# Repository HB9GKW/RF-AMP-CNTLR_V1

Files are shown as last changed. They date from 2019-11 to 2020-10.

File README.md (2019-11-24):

# RF-AMP-CNTLR_V1
HB9GKW RF Amplifier Controller

Features:

* Save sequencing of: 
	- Input and output relays with handshake and adjustable delays
	- Amplifier gate enable
	- ALC blanking voltage

* Control of up to 2 power amplifier modules

* Fast analog interlocking:
	- 4x VSWR
	- 2x RF input overload
	- Overcurrent
	- 2x Temperature

* High power MOSFET high side switch with voltage/current sense to disable amplifiers drain supply

* PTT input and adjustable ALC output

* Digital monitoring interface compatible for Raspberry Pi (40 pin header):
	- Amplifier operation and fault states
	- 12 ADC channels (12bit) for voltage, current, 4x forward/reflected, 2x temperature reading

* On-board power supplies (12V, -12V, 5V, 3.3V)

* Can be powered either by mains or external 13.8V supply

* Enhanced RF relay switching speed circuitry compatible for 12V and 24V RF relays

* Radio CAT control, Band and Antenna switching and general purpose interfacing ports for I2C and SPI

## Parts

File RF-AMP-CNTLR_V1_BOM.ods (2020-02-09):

Source: | RF-AMP-CNTLR_V1.sch
Date: | Sat 18 Jan 2020 12:43:05 PM CET
Tool: | Eeschema 5.1.5+dfsg1-2~bpo10+1
Generator: | /usr/share/kicad/plugins/bom_csv_grouped_by_value_with_fp.py
Component Count: | 375
Ref | Qnty | Value | Cmp name | Footprint | Description | Distributor | Distributor Order Number
C101, C106, C107, C114, C115, C116, C117, C118, C119, C123, C201, C203, C204, C205, C206, C207, C208, C209, C301, C310, C311, C312, C401, C402, C405, C406, C407, C408, C409, C410, C411, C412, C413, C414, C415, C416, C417, C418, C419, C423, C427, | 41 | 100n | C | Capacitor_SMD:C_0805_2012Metric_Pad1.15x1.40mm_HandSolder | Unpolarized capacitor | Mouser
C102, C103, | 2 | 68n | C | Capacitor_THT:C_Rect_L13.0mm_W4.0mm_P10.00mm_FKS3_FKP3_MKS4 | Unpolarized capacitor | Mouser | R71VF26804030K (https://www.mouser.ch/ProductDetail/KEMET/R71VF26804030K)
C104, C105, C110, C111, C112, C113, C120, C121, C122, C202, | 10 | 47u | CP | Capacitor_Tantalum_SMD:CP_EIA-6032-28_Kemet-C | Polarized capacitor | Mouser
C108, C109, | 2 | 47n | C | Capacitor_THT:C_Rect_L7.0mm_W3.5mm_P5.00mm | Unpolarized capacitor | Mouser | MKP2J024701M00KSSD (https://www.mouser.ch/ProductDetail/WIMA/MKP2J024701M00KSSD?qs=sGAEpiMZZMv1cc3ydrPrF7l45uRd9dVhKRMPc5zgiSQ%3D)
C302, C303, C304, C305, C306, C307, C308, C309, C313, C314, C315, C316, | 12 | 47n | C | Capacitor_SMD:C_0805_2012Metric_Pad1.15x1.40mm_HandSolder | Unpolarized capacitor | Mouser
C403, C404, | 2 | 470u | CP | Capacitor_THT:CP_Radial_D22.0mm_P10.00mm_SnapIn | Polarized capacitor | Mouser | MAL215932471E3 (https://www.mouser.ch/ProductDetail/Vishay-BC-Components/MAL215932471E3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)
C420, C421, C424, C425, | 4 | 1u | C | Capacitor_SMD:C_0805_2012Metric_Pad1.15x1.40mm_HandSolder | Unpolarized capacitor | Mouser
C422, C426, | 2 | 4u7 | CP | Capacitor_Tantalum_SMD:CP_EIA-6032-28_Kemet-C | Polarized capacitor | Mouser
D101, | 1 | B80C800DM | B80C800DM | Diode_THT:Diode_Bridge_DIP-4_W7.62mm_P5.08mm | Glass Passivated Single-Phase Bridge Rectifier, 80V Vrms, 0.8A If, DIP-4 | Mouser | B80C800DM-E3/45 (https://www.mouser.ch/ProductDetail/Vishay-Semiconductors/B80C800DM-E3-45)
D102, D202, | 2 | Power, RP_ON | LED | LED_THT:LED_D3.0mm | Light emitting diode, green | Mouser
D103, D104, D309, | 3 | BAT54CW | BAT54CW | Package_TO_SOT_SMD:SOT-323_SC-70 | Dual schottky barrier diode, common cathode, SOT-323 | Mouser | BAT54CWT1G (https://www.mouser.ch/ProductDetail/ON-Semiconductor/BAT54CWT1G)
D201, | 1 | BAT54AW | BAT54AW | Package_TO_SOT_SMD:SOT-323_SC-70 | Dual schottky barrier diode, common anode, SOT-323 | Mouser | BAT54AWT1G (https://www.mouser.ch/ProductDetail/ON-Semiconductor/BAT54AWT1G)
D305, D306, D307, D308, D314, D315, D316, D317, D319, D403, D404, D406, D409, D410, D413, D414, | 16 | BZT52C4V7T-7 | BZT52C4V7T-7 | Diode_SMD:D_SOD-523 | 150mW Silicon Planar Zener Diode, 4.7V, SOD-523 | Mouser | BZT52C4V7T-7 (https://www.mouser.ch/ProductDetail/Diodes-Incorporated/BZT52C4V7T-7)
D301, D302, D303, D304, D310, D311, D312, D313, D318, | 9 | HSWR1, HSWR2, HSWR3, HSWR4, RF_OL, TEMP1, TEMP2, OC, FAULT | LED | LED_THT:LED_D3.0mm | Light emitting diode, red | Mouser
D401, | 1 | Z1SMA33 | Z1SMAxxx | Diode_SMD:D_SMA | 1000mW Zener Diode, SMA(DO-214AC) | Mouser | SZ1SMA33AT3G (https://www.mouser.ch/ProductDetail/Littelfuse/SZ1SMA33AT3G)
D402, D405, | 2 | DZ2S130X0L | DZ2S130X0L | Diode_SMD:D_SOD-523 | 150mW Silicon Planar Zener Diode, 13V, SOD-523 | Mouser | BZT52C13T-7 (https://www.mouser.ch/ProductDetail/Diodes-Incorporated/BZT52C13T-7)
D407, D408, D411, D412, | 4 | PMEG6010CEH | PMEG6010CEH | Diode_SMD:D_SOD-123 | 60V 1A very low Vf MEGA Schottky barrier rectifier, SOD-123 | Mouser | PMEG6010CEH,115 (https://www.mouser.ch/ProductDetail/Nexperia/PMEG6010CEH115)
F101, F102, | 2 | 0.1AT | Fuse | Fuse:Fuse_Littelfuse_372_D8.50mm | Fuse | Mouser | 37211000001 (https://www.mouser.ch/ProductDetail/Littelfuse/37211000001)
FL101, | 1 | EMI_Filter_CommonMode | EMI_Filter_CommonMode | Inductor_THT:Choke_Schaffner_RN202-04-8.8x18.2mm | EMI 2-inductor common mode filter | Mouser | RN202-0.6-02-4M4 (https://www.mouser.ch/ProductDetail/Schaffner/RN202-06-02-4M4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)
J101, J102, J110, J111, | 4 | VAC, VDC, RELAY RF OUT, RELAY RF IN, | Screw_Terminal_01x06 | TerminalBlock_Phoenix:TerminalBlock_Phoenix_MKDS-3-6-5.08_1x06_P5.08mm_Horizontal | Generic screw terminal, single row, 01x06, script generated (kicad-library-utils/schlib/autogen/connector/) | Mouser | 1729160 (https://www.mouser.de/ProductDetail/Phoenix-Contact/1729160)
J103, | 1 | ext_13V8 | Screw_Terminal_01x02 | TerminalBlock_Phoenix:TerminalBlock_Phoenix_MKDS-3-2-5.08_1x02_P5.08mm_Horizontal | Generic screw terminal, single row, 01x02, script generated (kicad-library-utils/schlib/autogen/connector/) | Mouser
J104, J123, J124, | 3 | Front Panel, AMP1, AMP2, | Conn_02x08_Odd_Even | Connector_Multicomp:Multicomp_MC9A12-1634_2x08_P2.54mm_Vertical | Generic connector, double row, 02x08, odd/even pin numbering scheme (row 1 odd numbers, row 2 even numbers), script generated (kicad-library-utils/schlib/autogen/connector/) | Mouser
J105, J107, J121, J122, | 4 | ANT_SWITCH, I2C0, I2C1, RS232, | Conn_01x06 | Connector_PinHeader_2.54mm:PinHeader_1x06_P2.54mm_Vertical | Generic connector, single row, 01x06, script generated (kicad-library-utils/schlib/autogen/connector/) | Mouser
J106, J120, | 2 | BAND_SELECT, SPI0 | Conn_01x08 | Connector_PinHeader_2.54mm:PinHeader_2x04_P2.54mm_Vertical | Generic connector, single row, 01x08, script generated (kicad-library-utils/schlib/autogen/connector/) | Mouser
J108, J109, J118, J119, | 4 | VDD_IN, VSS_IN, VDD_AMP, GND_AMP, | Screw_Terminal_01x01 | TerminalBlock_MetzConnect:TerminalBlock_MetzConnect_360425_1x01_Horizontal_ScrewM4.0_Boxed | Generic screw terminal, single row, 01x01, script generated (kicad-library-utils/schlib/autogen/connector/) | Mouser
J112, J113, J114, J115, J116, J117, | 6 | FWD3, REF3, FWD4, REF4, PTT, ALC, | Conn_Coaxial | Connector_Coaxial:SMA_Amphenol_132134_Vertical | coaxial connector (BNC, SMA, SMB, SMC, Cinch/RCA, ...) | Mouser
J201, | 1 | Raspberry_Pi_2_3 | Raspberry_Pi_2_3 | Connector_PinHeader_2.54mm:PinHeader_2x20_P2.54mm_Vertical | expansion header for Raspberry Pi 2 & 3 | Mouser
L101, L102, L103, L104, | 4 | 10u | L_Core_Ferrite | Inductor_SMD:L_TDK_SLF6045 | Inductor with ferrite core | Mouser
PS101, PS102, | 2 | IRM-20-12 | IRM-20-12 | Converter_ACDC:Converter_ACDC_MeanWell_IRM-20-xx_THT | 12V 1.8A 20W miniature AC-DC module-type power supply MeanWell | Mouser | IRM-20-12 (https://www.mouser.de/ProductDetail/MEAN-WELL/IRM-20-12)
PS103, | 1 | IRM-20-5 | IRM-20-5 | Converter_ACDC:Converter_ACDC_MeanWell_IRM-20-xx_THT | 5V 4A 20W miniature AC-DC module-type power supply MeanWell | Mouser | RM-20-5 (https://www.mouser.de/ProductDetail/MEAN-WELL/IRM-20-5)
PS104, | 1 | ITQ2412SA | ITQ2412SA | my-library-footprints:Converter_DCDC_XP_POWER-ITXxxxxSA_THT | XP Power 6W, 1000 VDC Isolated DC/DC Converter Module, Single Output Voltage 12V, ±500mA, 24V Input Voltage, SIP | Mouser | ITQ2412SA (https://www.mouser.de/ProductDetail/XP-Power/ITQ2412SA)
PS105, | 1 | ITQ2405SA | ITQ2405SA | my-library-footprints:Converter_DCDC_XP_POWER-ITXxxxxSA_THT | XP Power 6W, 1000 VDC Isolated DC/DC Converter Module, Single Output Voltage 5V, ±1200mA, 24V Input Voltage, SIP | Mouser | ITQ2405SA (https://www.mouser.de/ProductDetail/XP-Power/ITQ2405SA)
Q101, Q321, Q322, Q332, Q408, Q411, Q413, Q417, Q421, Q425, | 10 | DTA124E | DTA124E | Package_TO_SOT_SMD:SOT-23 | Digital PNP Transistor, 22k/22k, SOT-23 | Mouser | PDTA124ET,215 (https://www.mouser.ch/ProductDetail/Nexperia/PDTA124ET215)
Q201, Q202, | 2 | BSS138 | BSS138 | Package_TO_SOT_SMD:SOT-23 | 50V Vds, 0.22A Id, N-Channel MOSFET, SOT-23 | Mouser | BSS138LT7G (https://www.mouser.de/ProductDetail/ON-Semiconductor/BSS138LT7G)
Q301, Q302, Q303, Q304, Q305, Q306, Q307, Q308, Q309, Q310, Q311, Q312, Q317, Q318, Q319, Q320, Q323, Q324, Q404, | 19 | BC857 | BC857 | Package_TO_SOT_SMD:SOT-23 | 0.1A Ic, 45V Vce, PNP Transistor, SOT-23 | Mouser
Q313, Q314, Q315, Q316, Q325, Q326, Q327, Q328, Q329, Q330, Q331, Q403, Q405, Q406, Q407, Q409, Q410, Q414, Q415, Q418, Q419, Q422, Q423, Q424, Q427, Q428, Q429, | 27 | DTC124E | DTC124E | Package_TO_SOT_SMD:SOT-23 | Digital NPN Transistor, 22k/22k, SOT-23 | Mouser | PDTC124ET,215 (https://www.mouser.ch/ProductDetail/Nexperia/PDTC124ET215)
Q401, Q402, | 2 | IXTH140P10T | SUD50P08-25L | Package_TO_SOT_THT:TO-247-3_Vertical | 50A Id, 80V Vds, TrenchFET P-Channel Power MOSFET, 25.2mOhm Ron, 160nC Qg, -55 to 175 °C, TO-252-2 | Mouser | IXTH140P10T (https://www.mouser.de/ProductDetail/IXYS/IXTH140P10T)
Q412, Q416, Q420, Q426, | 4 | BCX53 | BCX53 | Package_TO_SOT_SMD:SOT-89-3 | 1A Ic, 80V Vce, PNP Medium Power Transistor, SOT-89 | Mouser | BCX53-16TX (https://www.mouser.de/ProductDetail/Nexperia/BCX53-16TX)
R101, R325, R326, R327, R328, R333, R334, R335, R336, R363, R364, R365, R366, R378, | 14 | 22k | R | Resistor_SMD:R_0805_2012Metric_Pad1.15x1.40mm_HandSolder | Resistor | Mouser
R102, R377, R412, R415, R417, R424, R425, R432, R433, R434, R435, R436, R437, | 13 | 1k | R | Resistor_SMD:R_0805_2012Metric_Pad1.15x1.40mm_HandSolder | Resistor | Mouser
R103, | 1 | 620 | R | Resistor_SMD:R_0805_2012Metric_Pad1.15x1.40mm_HandSolder | Resistor | Mouser
R104, R201, R202, | 3 | 2k2 | R | Resistor_SMD:R_0805_2012Metric_Pad1.15x1.40mm_HandSolder | Resistor | Mouser
R203, | 1 | 1k5 | R | Resistor_SMD:R_0805_2012Metric_Pad1.15x1.40mm_HandSolder | Resistor | Mouser
R204, R205, R206, | 3 | 2k7 | R | Resistor_SMD:R_0805_2012Metric_Pad1.15x1.40mm_HandSolder | Resistor | Mouser
R207, R208, | 2 | 1k8 | R | Resistor_SMD:R_0805_2012Metric_Pad1.15x1.40mm_HandSolder | Resistor | Mouser
R301, R302, R303, R304, R305, R306, R307, R308, R353, R356, R359, R360, R361, R362, R403, R409, R414, | 17 | 100k | R | Resistor_SMD:R_0805_2012Metric_Pad1.15x1.40mm_HandSolder | Resistor | Mouser
R309, R310, R311, R312, R350, R352, | 6 | 15k | R | Resistor_SMD:R_0805_2012Metric_Pad1.15x1.40mm_HandSolder | Resistor | Mouser
R313, R314, R315, R316, | 4 | 82k | R | Resistor_SMD:R_0805_2012Metric_Pad1.15x1.40mm_HandSolder | Resistor | Mouser
R317, R318, R319, R320, R349, R351, R354, R357, R379, R411, R418, R421, R426, R429, | 14 | 47k | R | Resistor_SMD:R_0805_2012Metric_Pad1.15x1.40mm_HandSolder | Resistor | Mouser
R321, R322, R323, R324, R337, R339, R341, R343, R355, R358, R367, R371, R404, R410, R413, R419, R420, R422, R423, R427, R428, R430, R431, | 23 | 10k | R | Resistor_SMD:R_0805_2012Metric_Pad1.15x1.40mm_HandSolder | Resistor | Mouser
R329, R330, R331, R332, | 4 | 820k | R | Resistor_SMD:R_0805_2012Metric_Pad1.15x1.40mm_HandSolder | Resistor | Mouser
R338, R340, R342, R344, R368, R369, R370, R372, R380, R407, | 10 | 4k7 | R | Resistor_SMD:R_0805_2012Metric_Pad1.15x1.40mm_HandSolder | Resistor | Mouser
R345, R346, R347, R348, R373, R374, R375, R376, R381, | 9 | 470 | R | Resistor_SMD:R_0805_2012Metric_Pad1.15x1.40mm_HandSolder | Resistor | Mouser
R401, R402, R405, | 3 | 0R015 | R | Resistor_SMD:R_Shunt_Vishay_WSR2_WSR3_KelvinConnection | Resistor | Mouser | WSR3R0150FEB (https://www.mouser.ch/ProductDetail/Vishay-Dale/WSR3R0150FEB)
R406, | 1 | 6k8 | R | Resistor_SMD:R_0805_2012Metric_Pad1.15x1.40mm_HandSolder | Resistor | Mouser
R408, | 1 | 68k | R | Resistor_SMD:R_0805_2012Metric_Pad1.15x1.40mm_HandSolder | Resistor | Mouser
R416, | 1 | 33k | R | Resistor_SMD:R_0805_2012Metric_Pad1.15x1.40mm_HandSolder | Resistor | Mouser
RV301, RV302, RV303, RV304, RV305, RV306, RV307, RV308, | 8 | 50k | R_POT_TRIM | Potentiometer_THT:Potentiometer_Bourns_3296W_Vertical | Trim-potentiometer | Mouser
RV401, RV402, RV403, RV404, RV405, | 5 | 20k | R_POT_TRIM | Potentiometer_THT:Potentiometer_Bourns_3296W_Vertical | Trim-potentiometer | Mouser
SW301, | 1 | RESET | SW_Push | Button_Switch_THT:SW_PUSH_6mm | Push button switch, generic, two pins | Mouser
U101, | 1 | KA378R12C | KA378R12C | Package_TO_SOT_THT:TO-220-4_Vertical | Positive 3A 35V Linear Regulator with Disable Pin, LDO, Fixed Output 12V, TO-220F-4L | Mouser | obsolete | KIA378R12PI | eBay | MIC29301-12WT
U102, | 1 | SFH617A-2 | SFH617A-2 | Package_DIP:DIP-4_W7.62mm | Optocoupler, Phototransistor Output, 5300 VRMS, VCEO 70V, CTR% 63-125, -55 to +110 degree Celcius, UL, BSI, FIMKO, cUL, THT PDIP-4 | Mouser | VO617A-2 (https://www.mouser.de/ProductDetail/Vishay-Semiconductors/VO617A-2)
U103, | 1 | L78L33_SOT89 | L78L33_SOT89 | Package_TO_SOT_SMD:SOT-89-3 | Positive 100mA 30V Linear Regulator, Fixed Output 3.3V, SOT-89 | Mouser | L78L33ABUTR (https://www.mouser.de/ProductDetail/STMicroelectronics/L78L33ABUTR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)
U201, | 1 | MCP23017_SO | MCP23017_SO | Package_SO:SOIC-28W_7.5x17.9mm_P1.27mm | 16-bit I/O expander, I2C, interrupts, w pull-ups, SOIC-28 | Mouser | MCP23017-E/SO (https://www.mouser.de/ProductDetail/Microchip-Technology/MCP23017-E-SO)
U202, | 1 | MAX11616 | MAX11616 | Package_SO:QSOP-16_3.9x4.9mm_P0.635mm | 12-channel single-ended or 6-channel, differential, 12-bit ADC, I2C, 4.096V internal reference, 16-QSOP package | Mouser | MAX11616EEE+ (https://www.mouser.de/ProductDetail/Maxim-Integrated/MAX11616EEE%2B)
U203, | 1 | MAX3232 | MAX3232 | Package_SO:SOIC-18W_7.5x11.6mm_P1.27mm | 3.0V to 5.5V, Low-Power, up to 1Mbps, True RS-232 Transceivers Using Four 0.1μF External Capacitors | Mouser | MAX3222CWN+T (https://www.mouser.ch/ProductDetail/Maxim-Integrated/MAX3222CWN%2BT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)
U301, U304, U404, | 3 | LM339 | LM339 | Package_SO:SOIC-14_3.9x8.7mm_P1.27mm | Quad Differential Comparators, DIP-14/SOIC-14/SSOP-14 | Mouser | LM339DT (https://www.mouser.de/ProductDetail/STMicroelectronics/LM339DT?qs=sGAEpiMZZMsmUjwTDAf1t%252Bwcp%2FHLv31N)
U302, U303, U402, | 3 | MC33079 | MC33079 | Package_SO:SOIC-14_3.9x8.7mm_P1.27mm | Low Noise, Quad Operational Amplifiers, DIP-14/SOIC-14 | Mouser | MC33079DR2G (https://www.mouser.de/ProductDetail/ON-Semiconductor/MC33079DR2G?qs=sGAEpiMZZMtqO%252BWUGLBzeDrZ6oZu72DA)
U401, | 1 | MC33078 | MC33078 | Package_SO:SOIC-8_3.9x4.9mm_P1.27mm | Low Noise, Dual Operational Amplifiers, DIP-8/SOIC-8/SSOP-8 | Mouser | MC33078DR2G (https://www.mouser.de/ProductDetail/ON-Semiconductor/MC33078DR2G?qs=sGAEpiMZZMtqO%252BWUGLBzeFSiTRByazFb)
U403, | 1 | INA138 | INA138 | Package_TO_SOT_SMD:SOT-23-5 | High-Side Measurement Current Shunt Monitor, 36V, SOT-23-5 | Mouser | INA138NA/3K (https://www.mouser.de/ProductDetail/Texas-Instruments/INA138NA-3K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)

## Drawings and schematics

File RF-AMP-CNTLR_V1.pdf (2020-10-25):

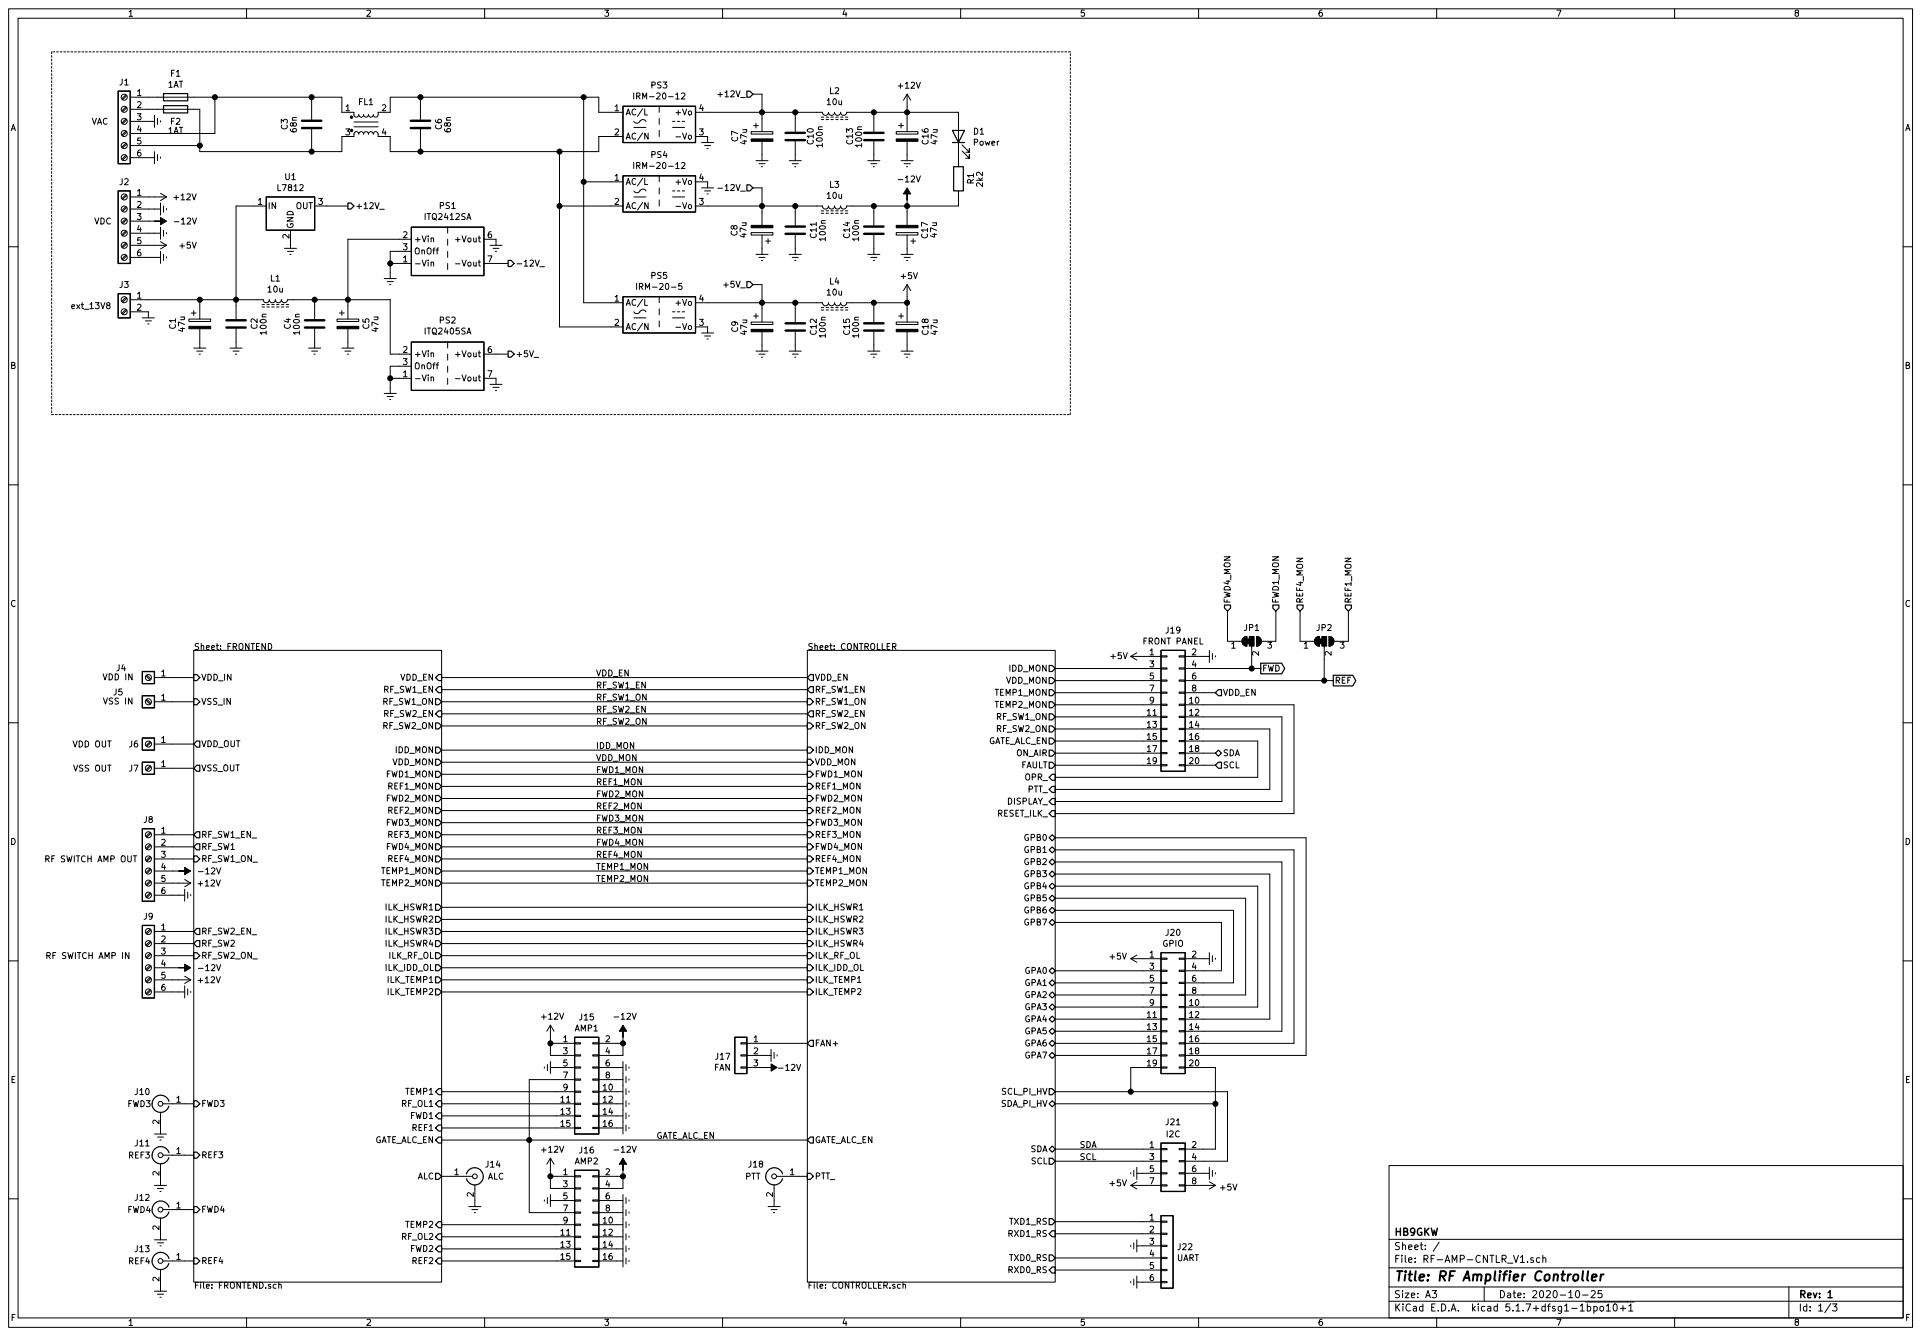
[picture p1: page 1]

RF_SW2_ON | | 13 | | 14
IDD_MON | | 15 | | 16

11 | 12
13 | 14
15 | 16
17 | 18

File: RF-AMP-CNTLR_V1.sch Sheet: / HB9GKW

Id: 1/3 Title: RF Amplifier Controller

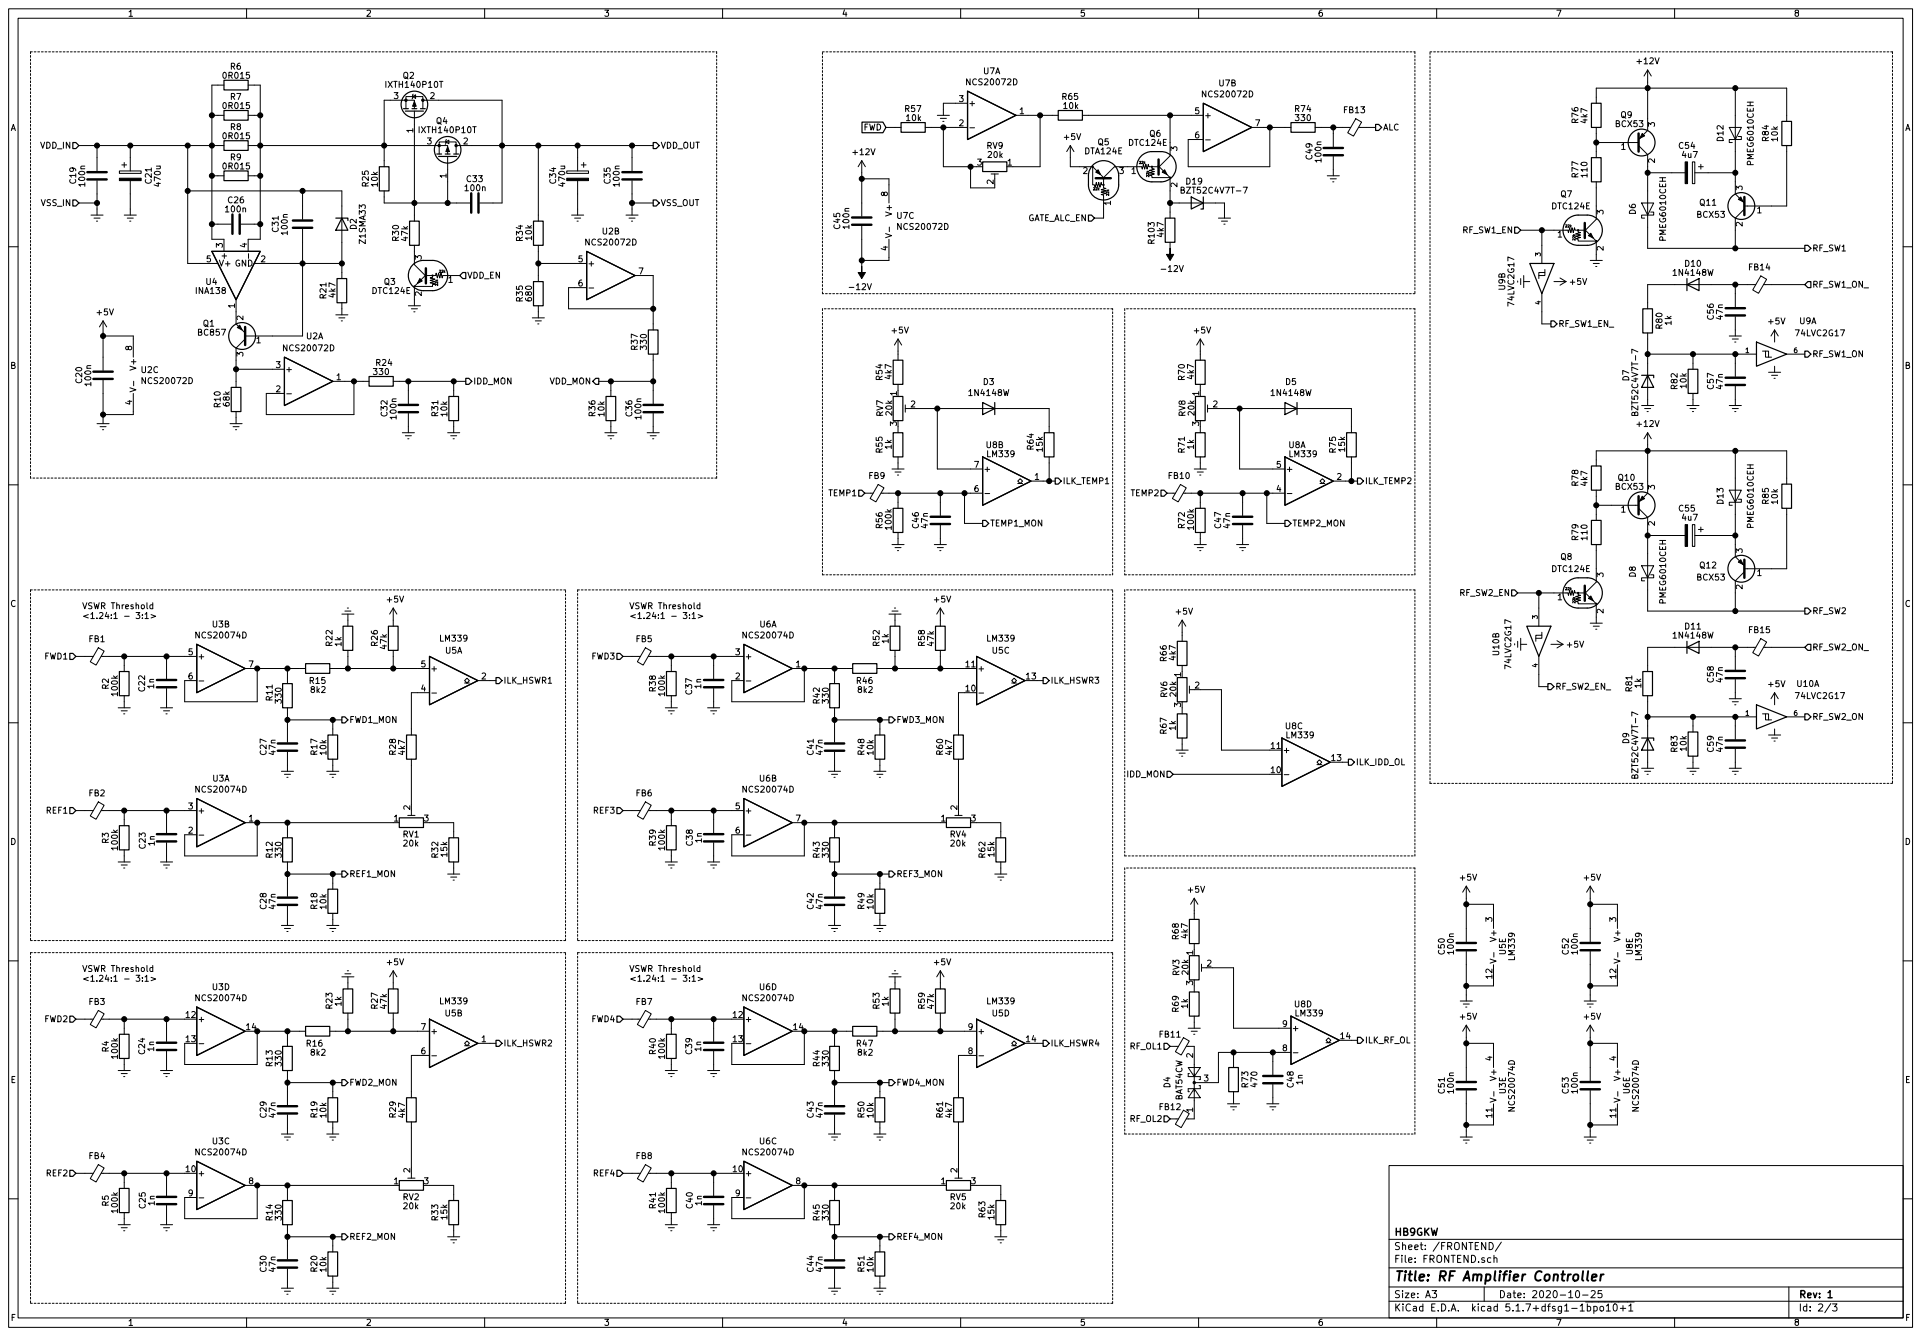
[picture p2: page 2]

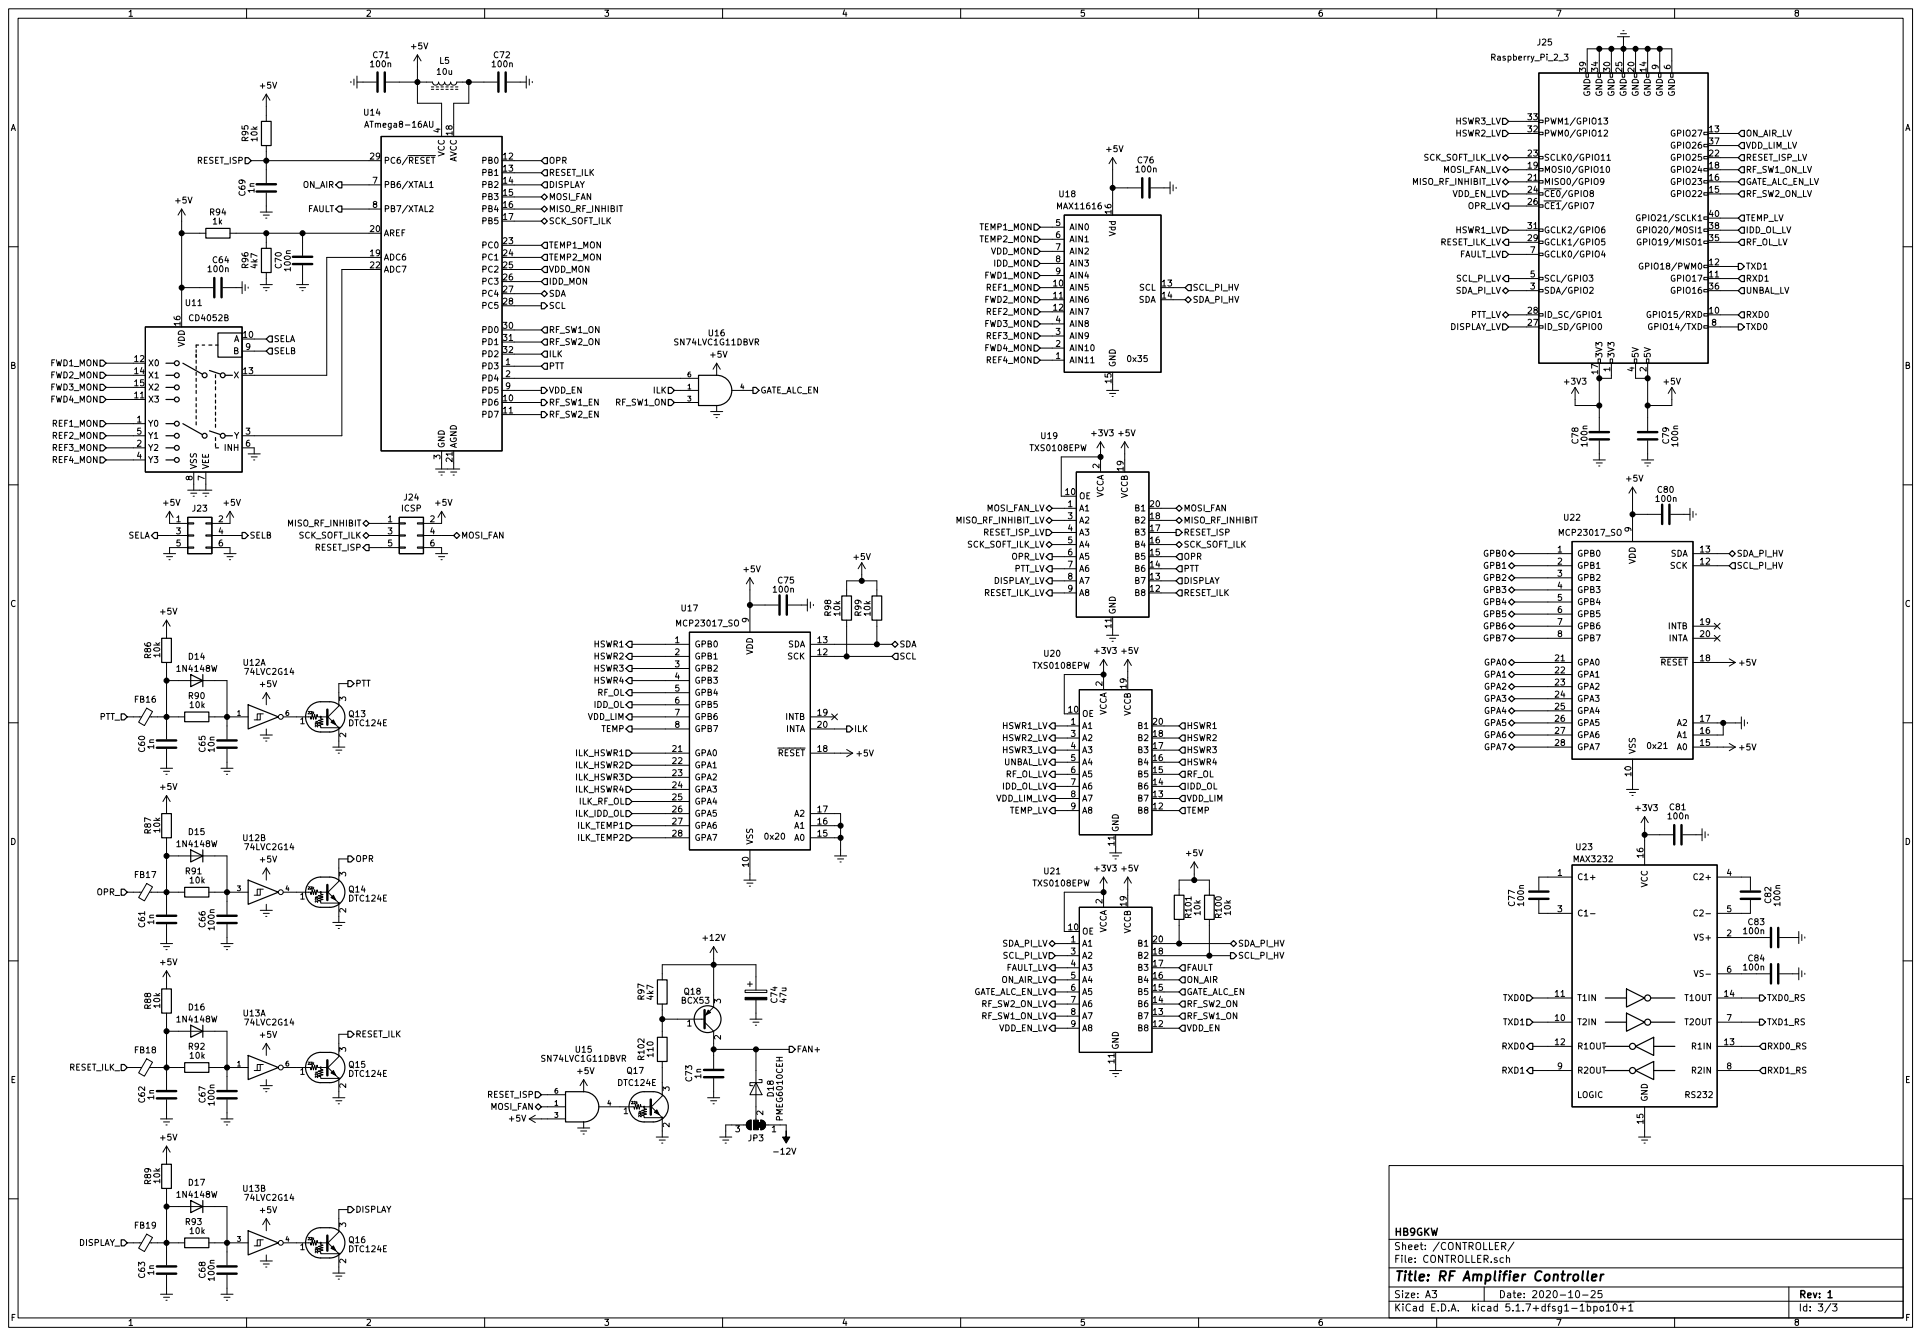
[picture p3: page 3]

Id: 3/3 Title: RF Amplifier Controller File: CONTROLLER.sch Sheet: /CONTROLLER/ HB9GKW

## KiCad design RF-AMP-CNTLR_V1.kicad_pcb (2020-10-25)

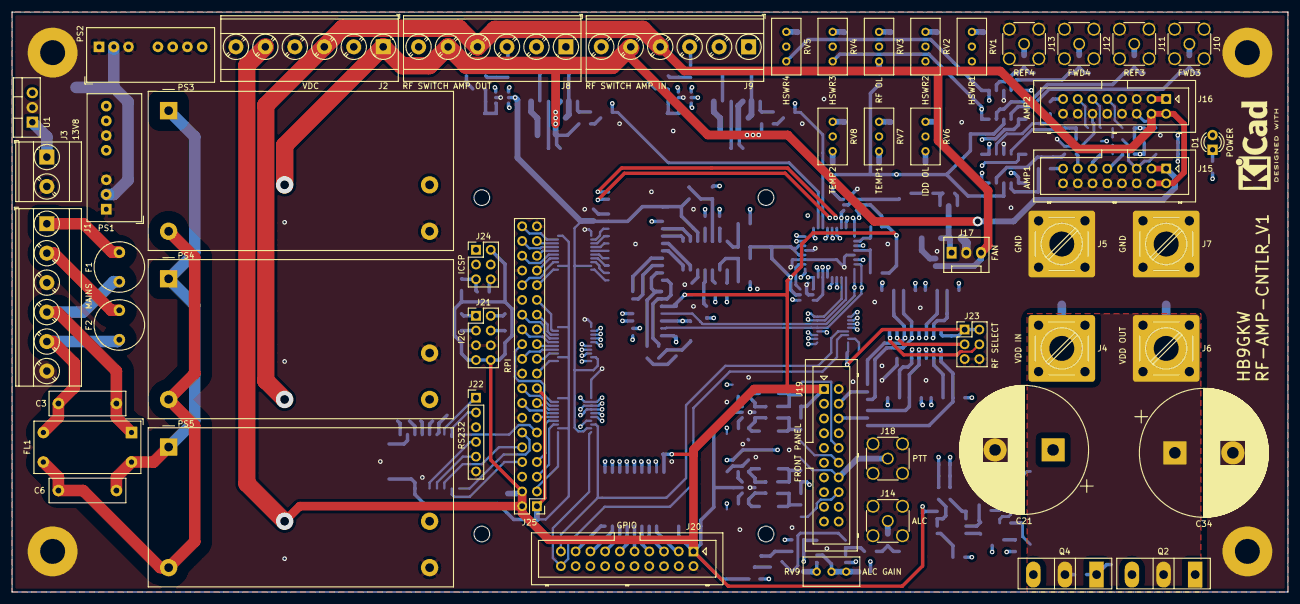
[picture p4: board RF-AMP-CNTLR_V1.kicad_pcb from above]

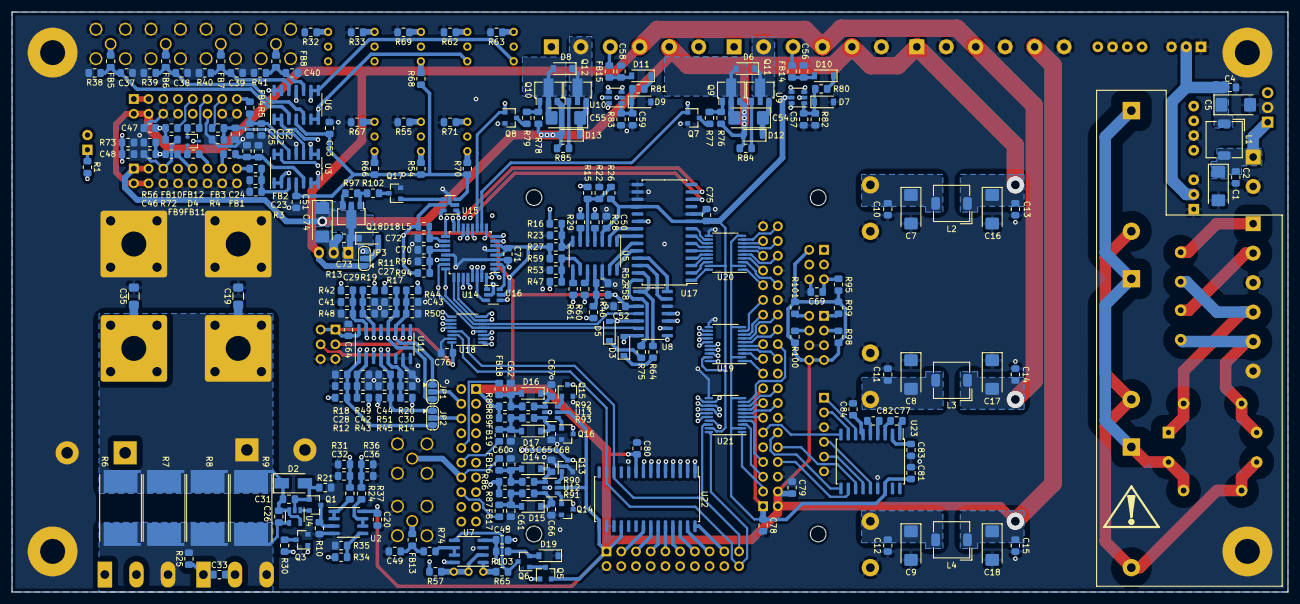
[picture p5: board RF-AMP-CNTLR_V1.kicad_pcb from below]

Board: 4 copper layers, 220.0 x 100.0 mm, 316 parts (266 on the bottom side), 252 nets.

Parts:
C1, C5, C7, C8, C9, C16, C17, C18, C74: 47u; CP_EIA-6032-28_Kemet-C
C2, C4, C10, C11, C12, C13, C14, C15, C20, C26, C31, C32, C33, C36, C45, C49, C50, C51, C52, C53, C64, C66, C67, C68, C70, C71, C72, C75, C76, C77, C78, C79, C80, C81, C82, C83, C84: 100n; C_0805_2012Metric_Pad1.15x1.40mm_HandSolder
C3, C6: 68n; C_Rect_L13.0mm_W4.0mm_P10.00mm_FKS3_FKP3_MKS4
C19, C35: 100n; C_1206_3216Metric_Pad1.42x1.75mm_HandSolder
C21, C34: 470u; CP_Radial_D22.0mm_P10.00mm_SnapIn
C22, C23, C24, C25, C37, C38, C39, C40, C48, C60, C61, C62, C63, C69, C73: 1n; C_0805_2012Metric_Pad1.15x1.40mm_HandSolder
C27, C28, C29, C30, C41, C42, C43, C44, C46, C47, C56, C57, C58, C59: 47n; C_0805_2012Metric_Pad1.15x1.40mm_HandSolder
C54, C55: 4u7; CP_EIA-6032-28_Kemet-C
C65: 10n; C_0805_2012Metric_Pad1.15x1.40mm_HandSolder
D1: Power; LED_D3.0mm
D2: Z1SMA33; D_SMA
D3, D5, D10, D11, D14, D15, D16, D17: 1N4148W; D_SOD-123
D4: BAT54CW; SOT-323_SC-70
D6, D8, D12, D13, D18: PMEG6010CEH; D_SOD-123
D7, D9, D19: BZT52C4V7T-7; D_SOD-123
F1, F2: 1AT; Fuse_Littelfuse_372_D8.50mm
FB1, FB2, FB3, FB4, FB5, FB6, FB7, FB8, FB9, FB10, FB11, FB12, FB13, FB14, FB15, FB16, FB17, FB18, FB19: Ferrite_Bead_Small; R_0805_2012Metric_Pad1.15x1.40mm_HandSolder
FL1: EMI_Filter_CommonMode; Choke_Schaffner_RN202-04-8.8x18.2mm
J1: VAC; TerminalBlock_Phoenix_MKDS-3-6-5.08_1x06_P5.08mm_Horizontal
J2: VDC; TerminalBlock_Phoenix_MKDS-3-6-5.08_1x06_P5.08mm_Horizontal
J3: ext_13V8; TerminalBlock_Phoenix_MKDS-3-2-5.08_1x02_P5.08mm_Horizontal
J4: VDD IN; TerminalBlock_MetzConnect_360425_1x01_Horizontal_ScrewM4.0_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
J5: VSS IN; TerminalBlock_MetzConnect_360425_1x01_Horizontal_ScrewM4.0_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
J6: VDD OUT; TerminalBlock_MetzConnect_360425_1x01_Horizontal_ScrewM4.0_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
J7: VSS OUT; TerminalBlock_MetzConnect_360425_1x01_Horizontal_ScrewM4.0_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
J8: RF SWITCH AMP OUT; TerminalBlock_Phoenix_MKDS-3-6-5.08_1x06_P5.08mm_Horizontal
J9: RF SWITCH AMP IN; TerminalBlock_Phoenix_MKDS-3-6-5.08_1x06_P5.08mm_Horizontal
J10: FWD3; SMA_Amphenol_132134_Vertical
J11: REF3; SMA_Amphenol_132134_Vertical
J12: FWD4; SMA_Amphenol_132134_Vertical
J13: REF4; SMA_Amphenol_132134_Vertical
J14: ALC; SMA_Amphenol_132134_Vertical
J15: AMP1; Multicomp_MC9A12-1634_2x08_P2.54mm_Vertical
J16: AMP2; Multicomp_MC9A12-1634_2x08_P2.54mm_Vertical
J17: FAN; FanPinHeader_1x03_P2.54mm_Vertical
J18: PTT; SMA_Amphenol_132134_Vertical
J19: FRONT PANEL; Multicomp_MC9A12-2034_2x10_P2.54mm_Vertical
J20: GPIO; Multicomp_MC9A12-2034_2x10_P2.54mm_Vertical
J21: I2C; PinHeader_2x04_P2.54mm_Vertical
J22: UART; PinHeader_1x06_P2.54mm_Vertical
J23: Conn_02x03_Odd_Even; PinHeader_2x03_P2.54mm_Vertical
J24: ICSP; PinHeader_2x03_P2.54mm_Vertical
J25: Raspberry_Pi_2_3; PinHeader_2x20_P2.54mm_Vertical
JP1, JP2, JP3: SolderJumper_3_Bridged12; SolderJumper-3_P1.3mm_Open_RoundedPad1.0x1.5mm
L1, L2, L3, L4: 10u; L_TDK_SLF6045
L5: 10u; L_0805_2012Metric
PS1: ITQ2412SA; Converter_DCDC_XP_POWER-ITXxxxxSA_THT
PS2: ITQ2405SA; Converter_DCDC_XP_POWER-ITXxxxxSA_THT
PS3, PS4: IRM-20-12; Converter_ACDC_MeanWell_IRM-20-xx_THT
PS5: IRM-20-5; Converter_ACDC_MeanWell_IRM-20-xx_THT
Q1: BC857; SOT-23
Q2, Q4: IXTH140P10T; TO-247-3_Vertical
Q3, Q6, Q7, Q8, Q13, Q14, Q15, Q16, Q17: DTC124E; SOT-23
Q5: DTA124E; SOT-23
Q9, Q10, Q11, Q12, Q18: BCX53; SOT-89-3
R1: 2k2; R_0805_2012Metric_Pad1.15x1.40mm_HandSolder
R2, R3, R4, R5, R38, R39, R40, R41, R56, R72: 100k; R_0805_2012Metric_Pad1.15x1.40mm_HandSolder
R6, R7, R8, R9: 0R015; R_Shunt_Vishay_WSR2_WSR3_KelvinConnection
R10: 68k; R_0805_2012Metric_Pad1.15x1.40mm_HandSolder
R11, R12, R13, R14, R24, R37, R42, R43, R44, R45, R74: 330; R_0805_2012Metric_Pad1.15x1.40mm_HandSolder
R15, R16, R46, R47: 8k2; R_0805_2012Metric_Pad1.15x1.40mm_HandSolder
R17, R18, R19, R20, R25, R31, R34, R36, R48, R49, R50, R51, R57, R65, R82, R83, R84, R85, R86, R87, R88, R89, R90, R91, R92, R93, R95, R98, R99, R100, R101: 10k; R_0805_2012Metric_Pad1.15x1.40mm_HandSolder
R21, R28, R29, R54, R60, R61, R66, R68, R70, R76, R78, R96, R97, R103: 4k7; R_0805_2012Metric_Pad1.15x1.40mm_HandSolder
R22, R23, R52, R53, R55, R67, R69, R71, R80, R81, R94: 1k; R_0805_2012Metric_Pad1.15x1.40mm_HandSolder
R26, R27, R30, R58, R59: 47k; R_0805_2012Metric_Pad1.15x1.40mm_HandSolder
R32, R33, R62, R63, R64, R75: 15k; R_0805_2012Metric_Pad1.15x1.40mm_HandSolder
R35: 680; R_0805_2012Metric_Pad1.15x1.40mm_HandSolder
R73: 470; R_0805_2012Metric_Pad1.15x1.40mm_HandSolder
R77, R79, R102: 110; R_0805_2012Metric_Pad1.15x1.40mm_HandSolder
RV1, RV2, RV3, RV4, RV5, RV6, RV7, RV8, RV9: 20k; Potentiometer_Bourns_3296W_Vertical
U1: L7812; TO-220-3_Vertical
U2, U7: NCS20072D; SOIC-8_3.9x4.9mm_P1.27mm
U3, U6: NCS20074D; SOIC-14_3.9x8.7mm_P1.27mm
U4: INA138; SOT-23-5
U5, U8: LM339; SOIC-14_3.9x8.7mm_P1.27mm
U9, U10: 74LVC2G17; SOT-23-6
U11: CD4052B; SOIC-16_3.9x9.9mm_P1.27mm
U12, U13: 74LVC2G14; SOT-23-6
U14: ATmega8-16AU; TQFP-32_7x7mm_P0.8mm
U15, U16: SN74LVC1G11DBVR; SOT-23-6
U17, U22: MCP23017_SO; SOIC-28W_7.5x17.9mm_P1.27mm
U18: MAX11616; QSOP-16_3.9x4.9mm_P0.635mm
U19, U20, U21: TXS0108EPW; TSSOP-20_4.4x6.5mm_P0.65mm
U23: MAX3232; SOIC-18W_7.5x11.6mm_P1.27mm

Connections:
+3V3: C78.1, C81.1, J25.1, J25.17, U19.2, U19.10, U20.2, U20.10, U21.2, U21.10, U23.16
+5V: C15.1, C18.1, C20.1, C50.1, C51.1, C52.1, C53.1, C64.1, C71.1, C75.1, C76.1, C79.1, C80.1, J2.5, J19.1, J20.1, J21.7, J21.8, J23.1, J23.2, J24.2, J25.2, J25.4, L4.1, L5.2, Q5.2, R26.2, R27.2, R54.1, R58.2, R59.2, R66.1, R68.1, R70.1, R86.1, R87.1, R88.1, R89.1, R94.2, R95.1, R98.2, R99.2, R100.2, R101.2, U2.8, U3.4, U5.3, U6.4, U8.3, U9.5, U10.5, U11.16, U12.5, U13.5, U14.4, U14.6, U15.3, U15.5, U16.5, U17.9, U17.18, U18.16, U19.19, U20.19, U21.19, U22.9, U22.15, U22.18
+12V: C13.1, C16.1, C45.1, C74.1, D1.2, D12.2, D13.2, J2.1, J8.5, J9.5, J15.1, J15.3, J16.1, J16.3, L2.1, Q9.3, Q10.3, Q18.3, R76.2, R78.2, R84.2, R85.2, R97.2, U7.8
-12V: C14.1, C17.2, C45.2, J2.3, J8.4, J9.4, J15.2, J15.4, J16.2, J16.4, J17.3, JP3.1, L3.1, R1.2, R103.2, U7.4
/+5V_: C9.1, C12.1, L4.2, PS2.6, PS5.4
/+12V_: C7.1, C10.1, L2.2, PS3.4, U1.3
/-12V_: C8.2, C11.1, L3.2, PS1.7, PS4.3
/CONTROLLER/DISPLAY: Q16.3, U14.14, U19.13
/CONTROLLER/DISPLAY_: FB19.2, J19.12
/CONTROLLER/DISPLAY_LV: J25.27, U19.8
/CONTROLLER/FAN+: C73.1, D18.1, J17.1, Q18.2
/CONTROLLER/FAULT: J19.19, U14.8, U21.17
/CONTROLLER/FAULT_LV: J25.7, U21.4
/CONTROLLER/GATE_ALC_EN_LV: J25.16, U21.6
/CONTROLLER/GPA0: J20.3, U22.21
/CONTROLLER/GPA1: J20.5, U22.22
/CONTROLLER/GPA2: J20.7, U22.23
/CONTROLLER/GPA3: J20.9, U22.24
/CONTROLLER/GPA4: J20.11, U22.25
/CONTROLLER/GPA5: J20.13, U22.26
/CONTROLLER/GPA6: J20.15, U22.27
/CONTROLLER/GPA7: J20.17, U22.28
/CONTROLLER/GPB0: J20.18, U22.1
/CONTROLLER/GPB1: J20.16, U22.2
/CONTROLLER/GPB2: J20.14, U22.3
/CONTROLLER/GPB3: J20.12, U22.4
/CONTROLLER/GPB4: J20.10, U22.5
/CONTROLLER/GPB5: J20.8, U22.6
/CONTROLLER/GPB6: J20.6, U22.7
/CONTROLLER/GPB7: J20.4, U22.8
/CONTROLLER/HSWR1: U17.1, U20.20
/CONTROLLER/HSWR1_LV: J25.31, U20.1
/CONTROLLER/HSWR2: U17.2, U20.18
/CONTROLLER/HSWR2_LV: J25.32, U20.3
/CONTROLLER/HSWR3: U17.3, U20.17
/CONTROLLER/HSWR3_LV: J25.33, U20.4
/CONTROLLER/HSWR4: U17.4, U20.16
/CONTROLLER/IDD_OL: U17.6, U20.14
/CONTROLLER/IDD_OL_LV: J25.38, U20.7
/CONTROLLER/ILK: U14.32, U16.1, U17.20
/CONTROLLER/ILK_HSWR1: U5.2, U17.21
/CONTROLLER/ILK_HSWR2: U5.1, U17.22
/CONTROLLER/ILK_HSWR3: U5.13, U17.23
/CONTROLLER/ILK_HSWR4: U5.14, U17.24
/CONTROLLER/ILK_IDD_OL: U8.13, U17.26
/CONTROLLER/ILK_RF_OL: U8.14, U17.25
/CONTROLLER/ILK_TEMP1: R64.2, U8.1, U17.27
/CONTROLLER/ILK_TEMP2: R75.2, U8.2, U17.28
/CONTROLLER/MISO_RF_INHIBIT: J24.1, U14.16, U19.18
/CONTROLLER/MISO_RF_INHIBIT_LV: J25.21, U19.3
/CONTROLLER/MOSI_FAN: J24.4, U14.15, U15.1, U19.20
/CONTROLLER/MOSI_FAN_LV: J25.19, U19.1
/CONTROLLER/ON_AIR: J19.17, U14.7, U21.16
/CONTROLLER/ON_AIR_LV: J25.13, U21.5
/CONTROLLER/OPR: Q14.3, U14.12, U19.15
/CONTROLLER/OPR_: FB17.2, J19.16
/CONTROLLER/OPR_LV: J25.26, U19.6
/CONTROLLER/PTT: Q13.3, U14.1, U19.14
/CONTROLLER/PTT_: FB16.2, J18.1, J19.14
/CONTROLLER/PTT_LV: J25.28, U19.7
/CONTROLLER/RESET_ILK: Q15.3, U14.13, U19.12
/CONTROLLER/RESET_ILK_: FB18.2, J19.10
/CONTROLLER/RESET_ILK_LV: J25.29, U19.9
/CONTROLLER/RESET_ISP: C69.1, J24.5, R95.2, U14.29, U15.6, U19.17
/CONTROLLER/RESET_ISP_LV: J25.22, U19.4
/CONTROLLER/RF_OL: U17.5, U20.15
/CONTROLLER/RF_OL_LV: J25.35, U20.6
/CONTROLLER/RF_SW1_ON_LV: J25.18, U21.8
/CONTROLLER/RF_SW2_ON_LV: J25.15, U21.7
/CONTROLLER/RXD0: J25.10, U23.12
/CONTROLLER/RXD0_RS: J22.5, U23.13
/CONTROLLER/RXD1: J25.11, U23.9
/CONTROLLER/RXD1_RS: J22.2, U23.8
/CONTROLLER/SCK_SOFT_ILK: J24.3, U14.17, U19.16
/CONTROLLER/SCK_SOFT_ILK_LV: J25.23, U19.5
/CONTROLLER/SCL_PI_HV: J20.19, J21.4, R100.1, U18.13, U21.18, U22.12
/CONTROLLER/SCL_PI_LV: J25.5, U21.3
/CONTROLLER/SDA_PI_HV: J20.20, J21.2, R101.1, U18.14, U21.20, U22.13
/CONTROLLER/SDA_PI_LV: J25.3, U21.1
/CONTROLLER/SELA: J23.3, U11.10
/CONTROLLER/SELB: J23.4, U11.9
/CONTROLLER/TEMP: U17.8, U20.12
/CONTROLLER/TEMP_LV: J25.40, U20.9
/CONTROLLER/TXD0: J25.8, U23.11
/CONTROLLER/TXD0_RS: J22.4, U23.14
/CONTROLLER/TXD1: J25.12, U23.10
/CONTROLLER/TXD1_RS: J22.1, U23.7
/CONTROLLER/UNBAL_LV: J25.36, U20.5
/CONTROLLER/VDD_EN_LV: J25.24, U21.9
/CONTROLLER/VDD_LIM: U17.7, U20.13
/CONTROLLER/VDD_LIM_LV: J25.37, U20.8
/FRONTEND/ALC: FB13.1, J14.1
/FRONTEND/FWD1: FB1.2, J15.13
/FRONTEND/FWD2: FB3.2, J16.13
/FRONTEND/FWD3: FB5.2, J10.1
/FRONTEND/FWD4: FB7.2, J12.1
/FRONTEND/REF1: FB2.2, J15.15
/FRONTEND/REF2: FB4.2, J16.15
/FRONTEND/REF3: FB6.2, J11.1
/FRONTEND/REF4: FB8.2, J13.1
/FRONTEND/RF_OL1: FB11.2, J15.11
/FRONTEND/RF_OL2: FB12.2, J16.11
/FRONTEND/RF_SW1: D6.1, J8.2, Q11.2
/FRONTEND/RF_SW1_EN_: J8.1, U9.4
/FRONTEND/RF_SW1_ON_: FB14.1, J8.3
/FRONTEND/RF_SW2: D8.1, J9.2, Q12.2
/FRONTEND/RF_SW2_EN_: J9.1, U10.4
/FRONTEND/RF_SW2_ON_: FB15.1, J9.3
/FRONTEND/TEMP1: FB9.2, J15.9
/FRONTEND/TEMP2: FB10.2, J16.9
/FRONTEND/VDD_IN: C19.1, C21.1, C26.2, C31.1, D2.1, J4.1, R6.2, R7.2, R8.2, R9.2, U4.3, U4.5
/FRONTEND/VDD_OUT: C33.2, C34.1, C35.1, J6.1, Q2.2, Q4.2, R34.1
/FWD1_MON: C27.1, JP1.3, R11.2, R17.2, U11.12, U18.9
/FWD2_MON: C29.1, R13.2, R19.2, U11.14, U18.11
/FWD3_MON: C41.1, R42.2, R48.2, U11.15, U18.4
/FWD4_MON: C43.1, JP1.1, R44.2, R50.2, U11.11, U18.2
/GATE_ALC_EN: J15.7, J16.7, J19.15, Q5.1, U16.4, U21.15
/IDD_MON: C32.1, J19.3, R24.1, R31.2, U8.10, U14.26, U18.8
/REF1_MON: C28.1, JP2.3, R12.2, R18.2, U11.1, U18.10
/REF2_MON: C30.1, R14.2, R20.2, U11.5, U18.12
/REF3_MON: C42.1, R43.2, R49.2, U11.2, U18.3
/REF4_MON: C44.1, JP2.1, R45.2, R51.2, U11.4, U18.1
/RF_SW1_EN: Q7.1, U9.3, U14.10
/RF_SW1_ON: J19.11, U9.6, U14.30, U16.3, U21.13
/RF_SW2_EN: Q8.1, U10.3, U14.11
/RF_SW2_ON: J19.13, U10.6, U14.31, U21.14
/SCL: J19.20, J21.3, R98.1, U14.28, U17.12
/SDA: J19.18, J21.1, R99.1, U14.27, U17.13
/TEMP1_MON: C46.1, FB9.1, J19.7, R56.1, U8.6, U14.23, U18.5
/TEMP2_MON: C47.1, FB10.1, J19.9, R72.1, U8.4, U14.24, U18.6
/VDD_EN: J19.8, Q3.1, U14.9, U21.12
/VDD_MON: C36.1, J19.5, R36.2, R37.2, U14.25, U18.7
Earth: C1.2, C2.2, C4.2, C5.2, C7.2, C8.1, C9.2, C10.2, C11.2, C12.2, C13.2, C14.2, C15.2, C16.2, C17.1, C18.2, C19.2, C20.2, C21.2, C22.2, C23.2, C24.2, C25.2, C27.2, C28.2, C29.2, C30.2, C32.2, C34.2, C35.2, C36.2, C37.2, C38.2, C39.2, C40.2, C41.2, C42.2, C43.2, C44.2, C46.2, C47.2, C48.2, C49.2, C50.2, C51.2, C52.2, C53.2, C56.2, C57.2, C58.2, C59.2, C60.2, C61.2, C62.2, C63.2, C64.2, C65.2, C66.2, C67.2, C68.2, C69.2, C70.2, C71.2, C72.2, C73.2, C74.2, C75.2, C76.2, C78.2, C79.2, C80.2, C81.2, C83.2, C84.2, D7.2, D9.2, D19.1, J1.3, J1.6, J2.2, J2.4, J2.6, J3.2, J5.1, J7.1, J8.6, J9.6, J10.2, J11.2, J12.2, J13.2, J14.2, J15.5, J15.6, J15.8, J15.10, J15.12, J15.14, J15.16, J16.5, J16.6, J16.8, J16.10, J16.12, J16.14, J16.16, J17.2, J18.2, J19.2, J20.2, J21.5, J21.6, J22.3, J22.6, J23.5, J23.6, J24.6, J25.6, J25.9, J25.14, J25.20, J25.25, J25.30, J25.34, J25.39, JP3.3, PS1.1, PS1.3, PS1.6, PS2.1, PS2.3, PS2.7, PS3.3, PS4.4, PS5.3, Q3.2, Q7.2, Q8.2, Q13.2, Q14.2, Q15.2, Q16.2, Q17.2, R2.2, R3.2, R4.2, R5.2, R10.2, R17.1, R18.1, R19.1, R20.1, R21.2, R22.2, R23.2, R31.1, R32.2, R33.2, R35.2, R36.1, R38.2, R39.2, R40.2, R41.2, R48.1, R49.1, R50.1, R51.1, R52.2, R53.2, R55.2, R56.2, R62.2, R63.2, R67.2, R69.2, R71.2, R72.2, R73.2, R82.2, R83.2, R96.2, U1.2, U2.4, U3.11, U5.12, U6.11, U7.3, U8.12, U9.2, U10.2, U11.6, U11.7, U11.8, U12.2, U13.2, U14.3, U14.5, U14.21, U15.2, U16.2, U17.10, U17.15, U17.16, U17.17, U18.15, U19.11, U20.11, U21.11, U22.10, U22.16, U22.17, U23.15
FWD: J19.4, JP1.2, R57.2
unnamed: C1.1, C2.1, J3.1, L1.2, U1.1
unnamed: C3.1, F1.1, FL1.1, J1.4
unnamed: C3.2, F2.1, FL1.3, J1.5
unnamed: C4.1, C5.1, L1.1, PS1.2, PS2.2
unnamed: C6.1, FL1.2, PS3.1, PS4.1, PS5.1
unnamed: C6.2, FL1.4, PS3.2, PS4.2, PS5.2
unnamed: C22.1, FB1.1, R2.1, U3.5
unnamed: C23.1, FB2.1, R3.1, U3.3
unnamed: C24.1, FB3.1, R4.1, U3.12
unnamed: C25.1, FB4.1, R5.1, U3.10
unnamed: C26.1, Q2.3, Q4.3, R6.1, R7.1, R8.1, R9.1, R25.2, U4.4
unnamed: C31.2, D2.2, Q1.1, R21.1, U4.2
unnamed: C33.1, Q2.1, Q4.1, R25.1, R30.2
unnamed: C37.1, FB5.1, R38.1, U6.3
unnamed: C38.1, FB6.1, R39.1, U6.5
unnamed: C39.1, FB7.1, R40.1, U6.12
unnamed: C40.1, FB8.1, R41.1, U6.10
unnamed: C48.1, D4.3, R73.1, U8.8
unnamed: C49.1, FB13.2, R74.1
unnamed: C54.1, D12.1, Q11.3
unnamed: C54.2, D6.2, Q9.2
unnamed: C55.1, D13.1, Q12.3
unnamed: C55.2, D8.2, Q10.2
unnamed: C56.1, D10.2, FB14.2
unnamed: C57.1, D7.1, R80.2, R82.1, U9.1
unnamed: C58.1, D11.2, FB15.2
unnamed: C59.1, D9.1, R81.2, R83.1, U10.1
unnamed: C60.1, D14.2, FB16.1, R86.2, R90.2
unnamed: C61.1, D15.2, FB17.1, R87.2, R91.2
unnamed: C62.1, D16.2, FB18.1, R88.2, R92.2
unnamed: C63.1, D17.2, FB19.1, R89.2, R93.2
unnamed: C65.1, D14.1, R90.1, U12.1
unnamed: C66.1, D15.1, R91.1, U12.3
unnamed: C67.1, D16.1, R92.1, U13.1
unnamed: C68.1, D17.1, R93.1, U13.3
unnamed: C70.1, R94.1, R96.1, U14.20
unnamed: C72.1, L5.1, U14.18
unnamed: C77.1, U23.1
unnamed: C77.2, U23.3
unnamed: C82.1, U23.4
unnamed: C82.2, U23.5
unnamed: C83.1, U23.2
unnamed: C84.1, U23.6
unnamed: D1.1, R1.1
unnamed: D3.1, R64.1
unnamed: D3.2, RV7.2, U8.7
unnamed: D4.1, FB12.1
unnamed: D4.2, FB11.1
unnamed: D5.1, R75.1
unnamed: D5.2, RV8.2, U8.5
unnamed: D10.1, R80.1
unnamed: D11.1, R81.1
unnamed: D18.2, JP3.2
unnamed: D19.2, Q6.2, R103.1
unnamed: F1.2, J1.1
unnamed: F2.2, J1.2
unnamed: Q1.2, U4.1
unnamed: Q1.3, R10.1, U2.3
unnamed: Q3.3, R30.1
unnamed: Q5.3, Q6.1
unnamed: Q6.3, R65.1, U7.5
unnamed: Q7.3, R77.1
unnamed: Q8.3, R79.1
unnamed: Q9.1, R76.1, R77.2
unnamed: Q10.1, R78.1, R79.2
unnamed: Q11.1, R84.1
unnamed: Q12.1, R85.1
unnamed: Q13.1, U12.6
unnamed: Q14.1, U12.4
unnamed: Q15.1, U13.6
unnamed: Q16.1, U13.4
unnamed: Q17.1, U15.4
unnamed: Q17.3, R102.1
unnamed: Q18.1, R97.1, R102.2
unnamed: R11.1, R15.2, U3.6, U3.7
unnamed: R12.1, RV1.1, U3.1, U3.2
unnamed: R13.1, R16.2, U3.13, U3.14
unnamed: R14.1, RV2.1, U3.8, U3.9
unnamed: R15.1, R22.1, R26.1, U5.5
unnamed: R16.1, R23.1, R27.1, U5.7
unnamed: R24.2, U2.1, U2.2
unnamed: R28.1, RV1.2
unnamed: R28.2, U5.4
unnamed: R29.1, RV2.2
unnamed: R29.2, U5.6
unnamed: R32.1, RV1.3
unnamed: R33.1, RV2.3
unnamed: R34.2, R35.1, U2.5
unnamed: R37.1, U2.6, U2.7
unnamed: R42.1, R46.2, U6.1, U6.2
unnamed: R43.1, RV4.1, U6.6, U6.7
unnamed: R44.1, R47.2, U6.13, U6.14
unnamed: R45.1, RV5.1, U6.8, U6.9
unnamed: R46.1, R52.1, R58.1, U5.11
unnamed: R47.1, R53.1, R59.1, U5.9
unnamed: R54.2, RV7.1
unnamed: R55.1, RV7.3
unnamed: R57.1, RV9.2, RV9.3, U7.2
unnamed: R60.1, RV4.2
unnamed: R60.2, U5.10
unnamed: R61.1, RV5.2
unnamed: R61.2, U5.8
unnamed: R62.1, RV4.3
unnamed: R63.1, RV5.3
unnamed: R65.2, RV9.1, U7.1
unnamed: R66.2, RV6.1
unnamed: R67.1, RV6.3
unnamed: R68.2, RV3.1
unnamed: R69.1, RV3.3
unnamed: R70.2, RV8.1
unnamed: R71.1, RV8.3
unnamed: R74.2, U7.6, U7.7
unnamed: RV3.2, U8.9
unnamed: RV6.2, U8.11
unnamed: U11.3, U14.22
unnamed: U11.13, U14.19
unnamed: U14.2, U16.6
REF: J19.6, JP2.2

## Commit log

2019-11-12 remove file
    [PCB - Copy.dxf]
2019-12-01 Review 1
    [CONTROLLER.sch, INTERLOCK.sch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]
2020-01-11 Review 2
    [CONTROLLER.sch, INTERLOCK.sch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]
2020-01-13 changing gerber format
    [RF-AMP-CNTLR_V1-B_Cu.gbr, RF-AMP-CNTLR_V1-B_Mask.gbr, RF-AMP-CNTLR_V1-B_SilkS.gbr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]
2020-02-03 prototype bug fixes
    [RF-AMP-CNTLR_V1-B_Cu.gbr, RF-AMP-CNTLR_V1-B_Mask.gbr, RF-AMP-CNTLR_V1-B_SilkS.gbr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]
2020-02-03 BOM entry fixes
    [RF-AMP-CNTLR_V1_BOM.ods]
2020-02-09 bug fixes
    [RF-AMP-CNTLR_V1_BOM.ods]
2020-07-17 new Version with AVR Controller
    [CONTROLLER.sch, INTERLOCK.sch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]
2020-08-24 forgot to update
    [FRONTEND.sch]
2020-08-24 remove unused
    [INTERLOCK.sch, SEQUENCER.sch]
2020-08-29 bug fix ITQ ON/OFF
    [RF-AMP-CNTLR_V1-B_Cu.gbr, RF-AMP-CNTLR_V1-B_Mask.gbr, RF-AMP-CNTLR_V1-B_SilkS.gbr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]
2020-08-30 bug fix level shifter U19-U21 VCCA VCCB swap
    [CONTROLLER.sch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]
2020-10-25 ALC latch-up fix
    [CONTROLLER.sch, FRONTEND.sch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]
